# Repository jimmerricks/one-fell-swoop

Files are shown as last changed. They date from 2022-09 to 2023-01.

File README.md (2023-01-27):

# Swoop

A WIP fork of [David Barr's Sweep](https://github.com/davidphilipbarr/Sweep), which is itself based on the fabulous [Ferris by Pierre Chevalier](https://github.com/pierrechevalier83/ferris).

<span>
  <a href="https://discord.com/invite/JxfcFuUGhR">
    
  </a>
  
</span>

## Swoop MX / Howarya 🦞

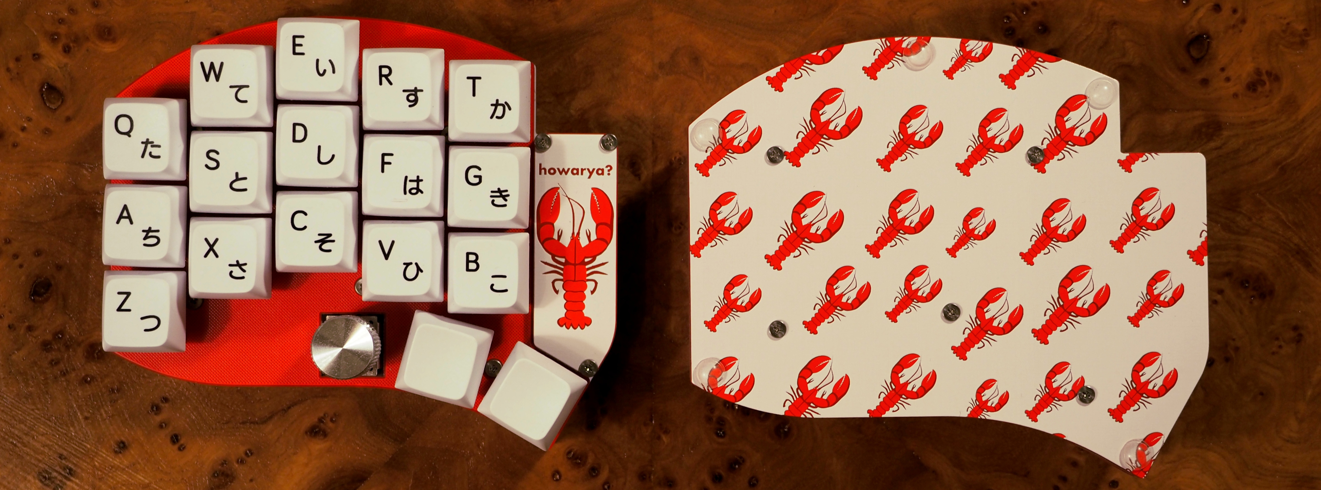
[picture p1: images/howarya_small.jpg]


| Front | Back |
| :---: | :---: |
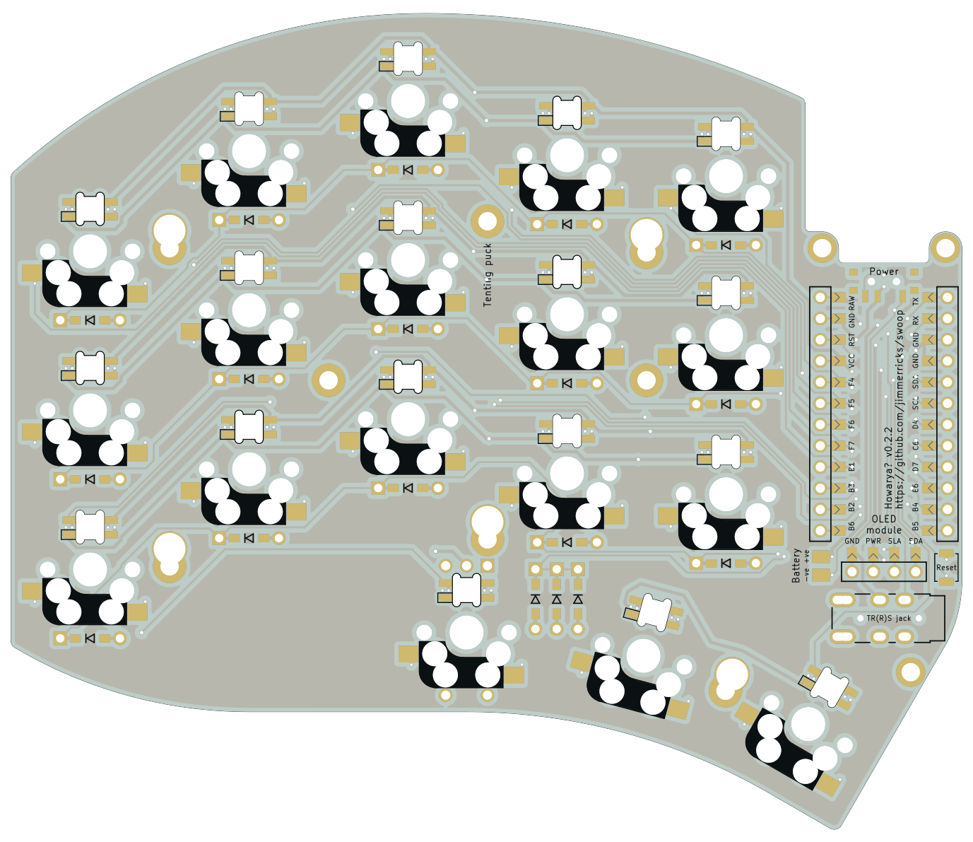
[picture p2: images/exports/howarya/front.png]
front
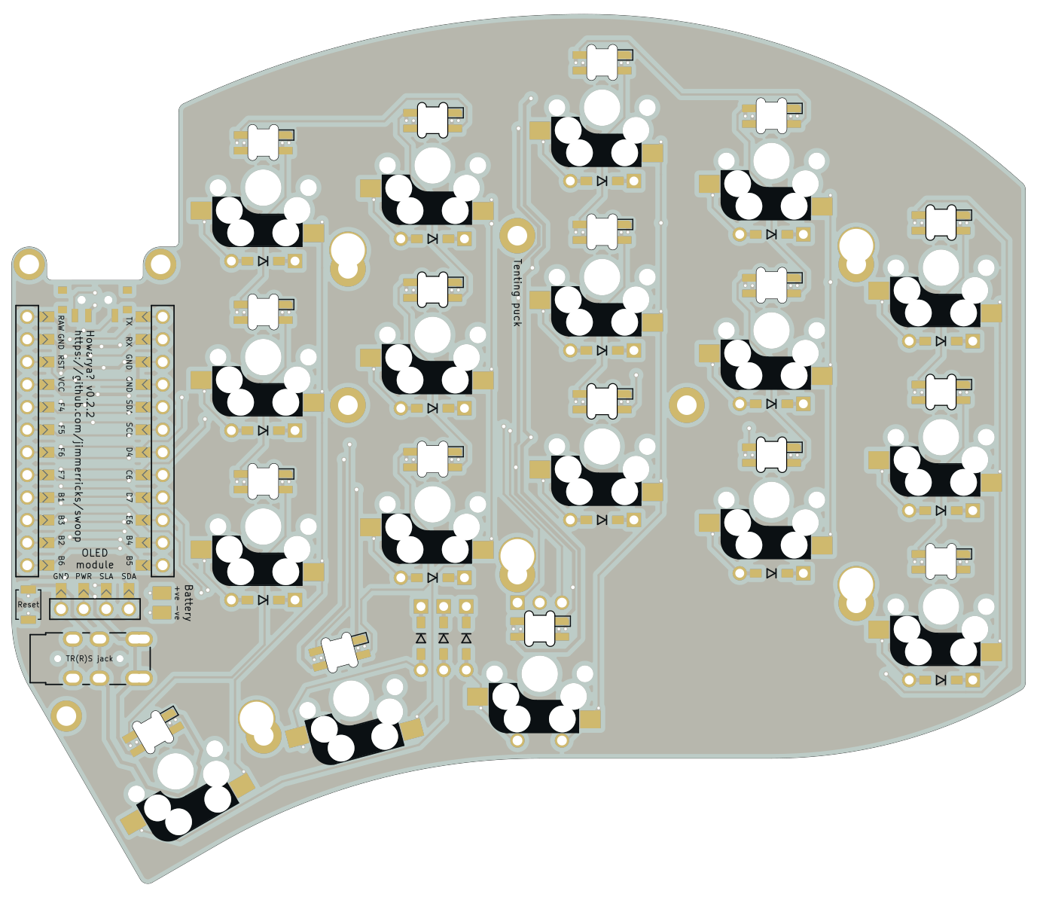
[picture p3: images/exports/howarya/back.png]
back
|  |  |

### Features
⭕ Cherry MX style switches  
⭕ Hotswap support  
⭕ Per-key RGB LEDs (mini-e)  
⭕ Up to 2 encoders  
⭕ Oled screens  
⭕ Power switch for battery management  
⭕ Bluetooth support w/ nice!nano  
⭕ Plate style case with mcu cover

### Components list

To build and use a Swoop MX you will need:

* 1× PCB Kit
* 2× promicro compatible boards or 2 nice!nanos.
* 34-36× Cherry MX style switches
* 34-36× Kailh hotswap sockets
* 34-36× SK6812 Mini-E RGB SMD Leds (optional; not recommended for wireless)
* 34-36× keycaps
* 36× diodes (Surface-mount or Through-hole)
* 2× Rotary encoders & knobs (optional; ALPS EC11)
* 2× OLED LCD Display 128x32 SSD1306 (optional)
* 2× reset switches (optional; B3U-1000P(M))
* Some little rubber feet/bumpers
* 2× power switches (wireless only; MSK 12C02)
* 2× lipo batteries (wireless only; 301230 or 301228)
* 1× TRRS (not TRS!) cable (wired only)
* 2× TRRS Jack [PJ-320A] (wired only)
* 1× USB Cable (depends on your micro-controller choice)  

**For the case:**

* 32× M2 Screws (3mm thread length)  
* 10× M2 Standoff for the plates (7mm)
* 6× M2 Standoff for the controller cover (8mm)

### How to build it

<a href="https://youtu.be/pvvNYPsMyz4" target="_blank">
  
</a>

### Firmware

The firmware is available in QMK as `bluebell/swoop`.  
You can get started by using QMK's [online configurator](https://config.qmk.fm/#/bluebell/swoop/LAYOUT_split_3x5_3). Or check the [Swoop README file](https://github.com/qmk/qmk_firmware/blob/master/keyboards/bluebell/swoop/readme.md) to see how to compile the firmware locally.

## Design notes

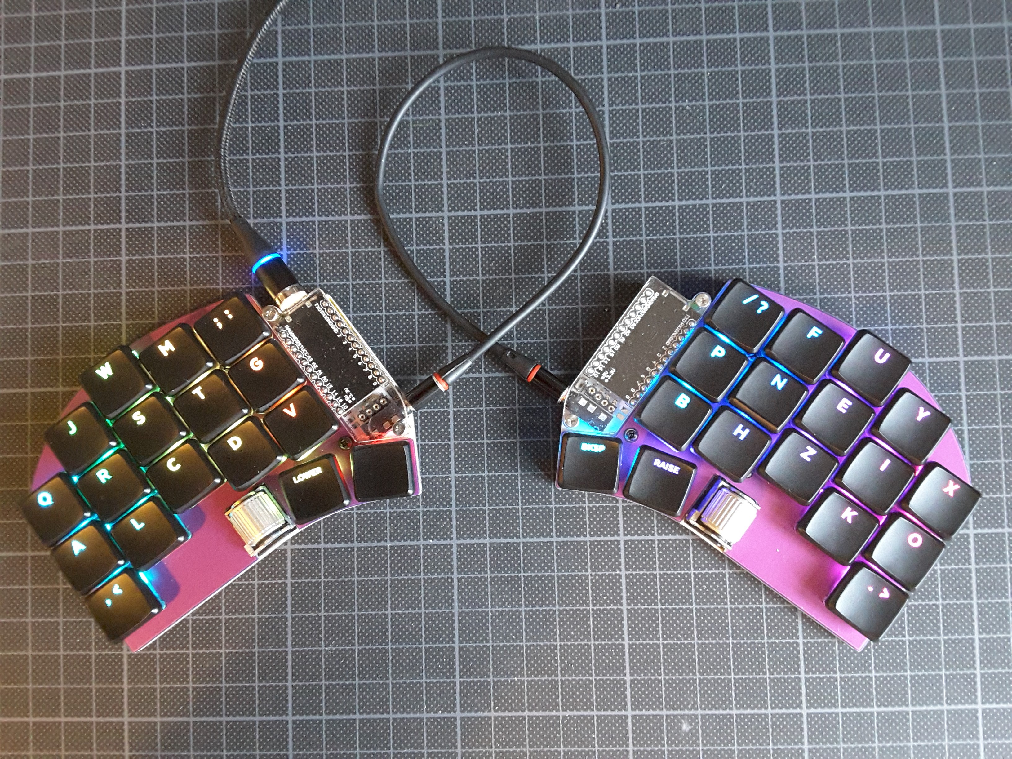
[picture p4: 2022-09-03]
images/swoop.jpg

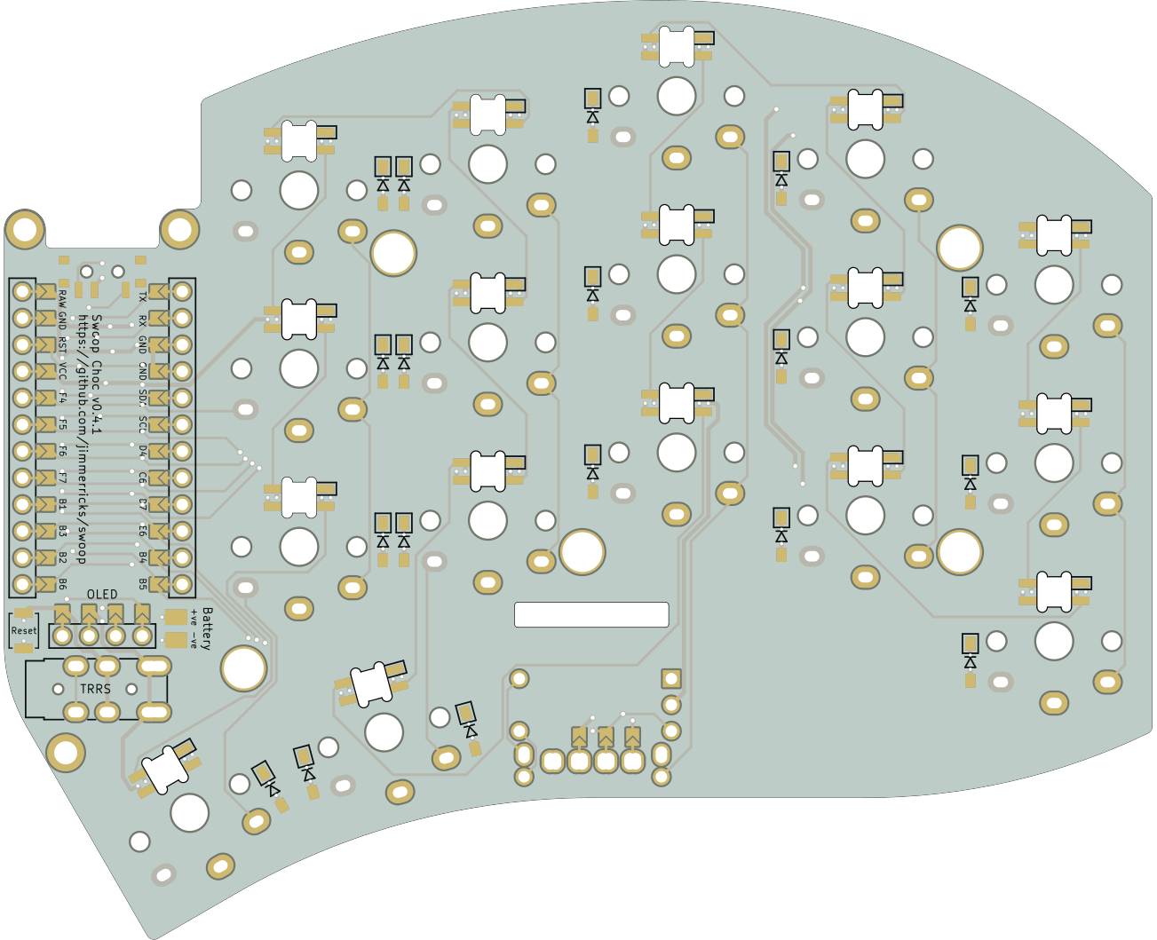
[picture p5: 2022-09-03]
images/exports/swoop/back.png

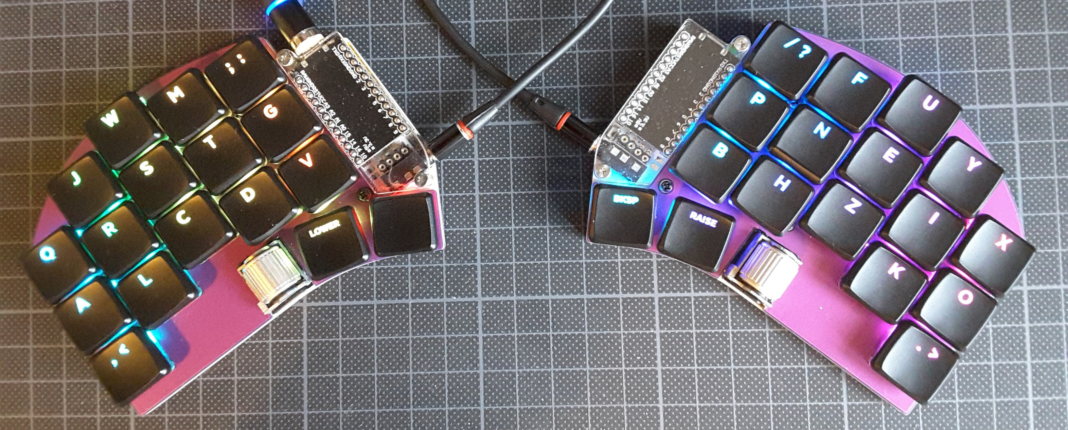
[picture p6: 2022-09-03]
images/swoop_small.jpg

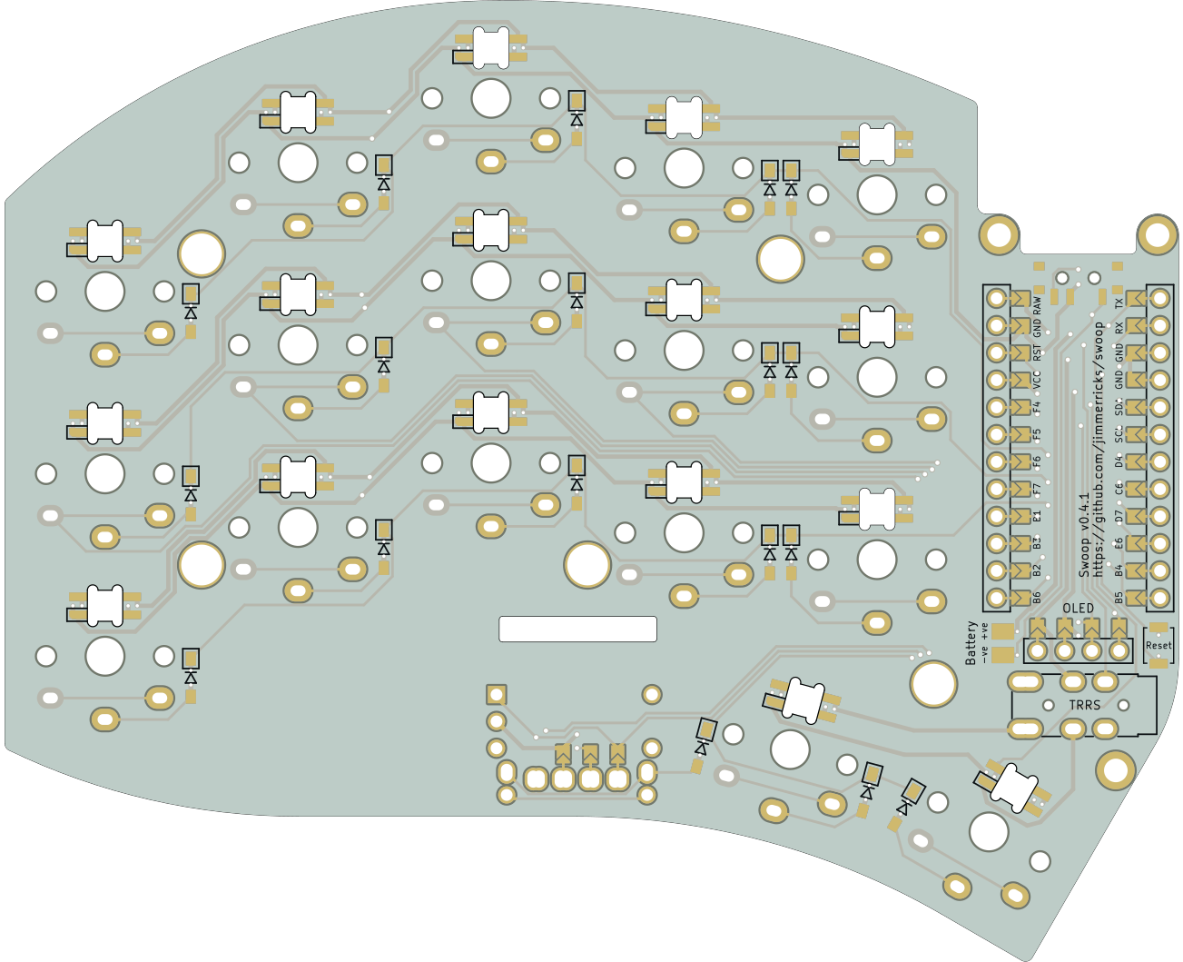
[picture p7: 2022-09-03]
images/exports/swoop/front.png

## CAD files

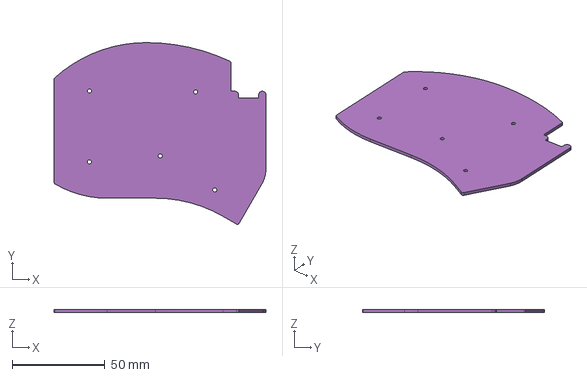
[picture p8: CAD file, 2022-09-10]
plates/swoop-mx/swoop-mx-base-plate/swoop-mx-plate-base-plate.step
114.0 x 97.8 x 1.60 mm

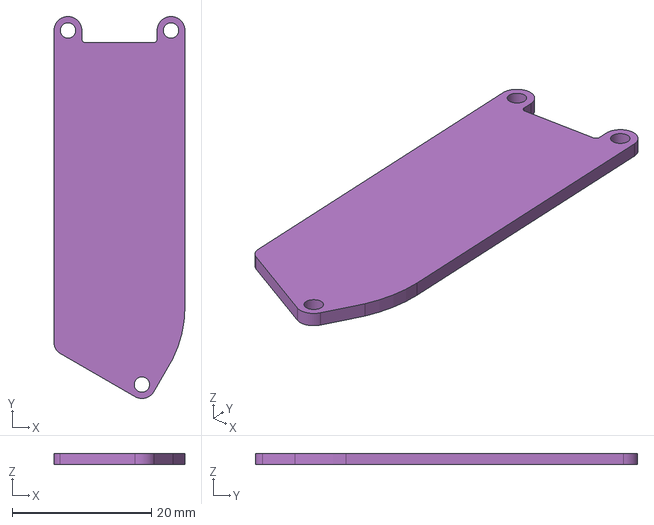
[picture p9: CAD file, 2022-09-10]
plates/swoop-mx/swoop-mx-cover/swoop-mx-plate-cover.step
18.8 x 54.8 x 1.60 mm

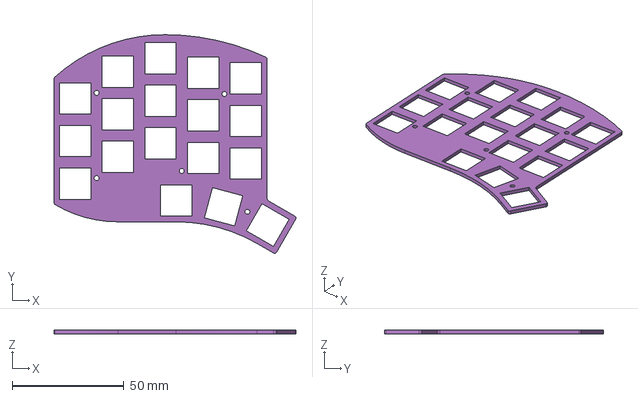
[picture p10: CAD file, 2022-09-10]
plates/swoop-mx/swoop-mx-switch-plate/swoop-mx-plate-switch-plate.step
108.2 x 97.8 x 1.60 mm

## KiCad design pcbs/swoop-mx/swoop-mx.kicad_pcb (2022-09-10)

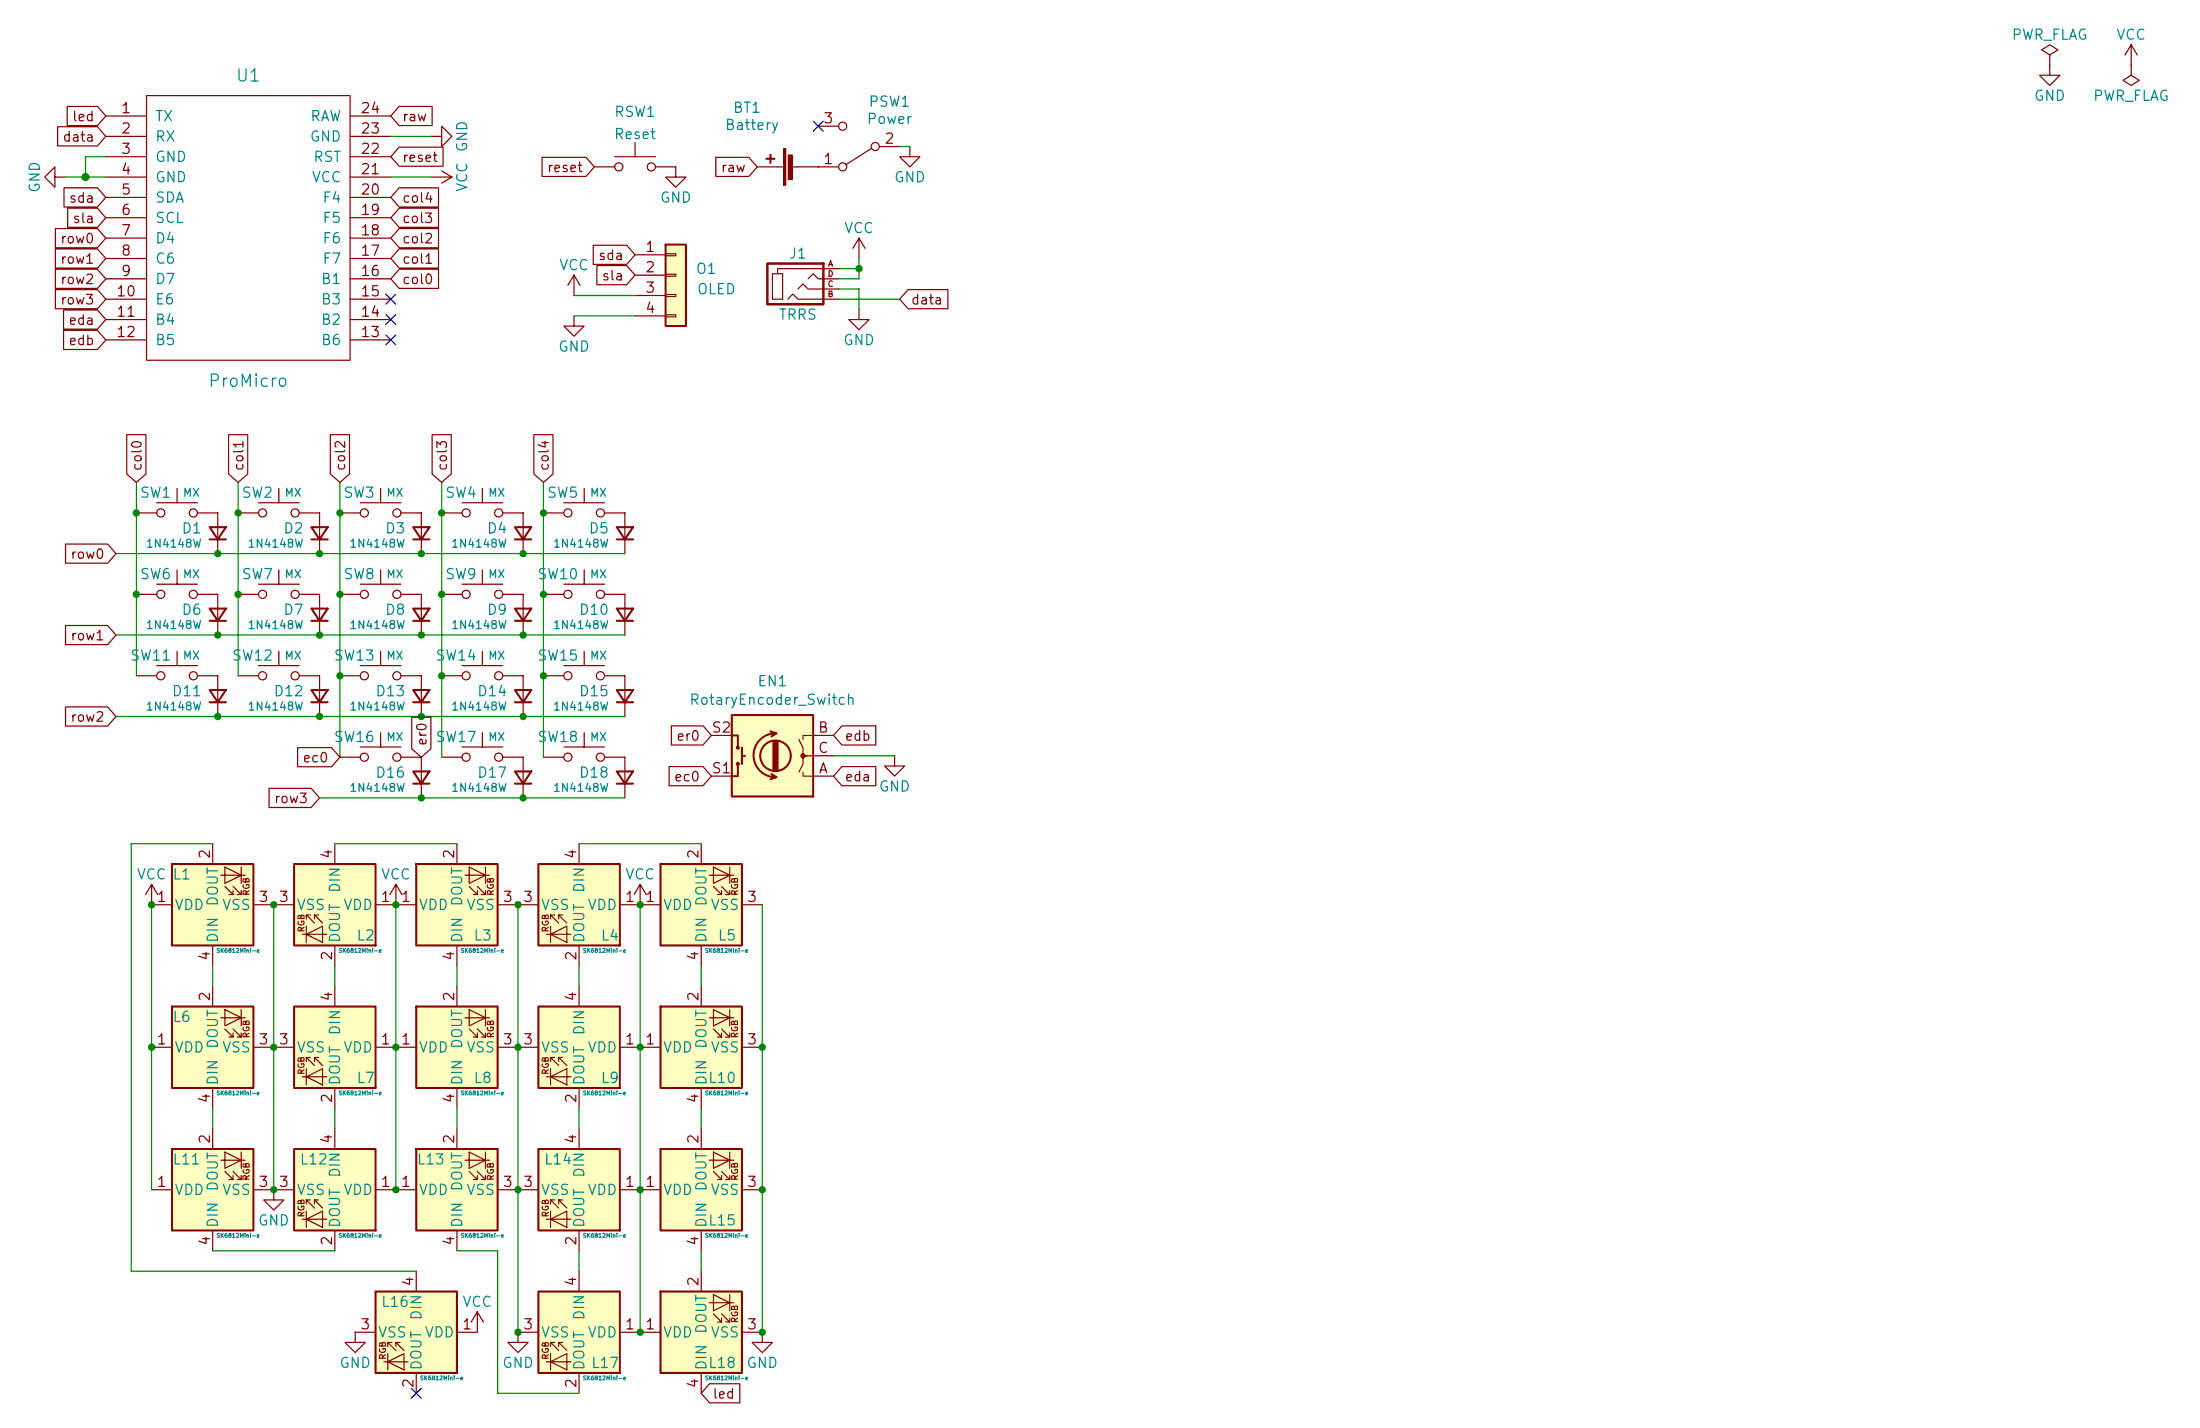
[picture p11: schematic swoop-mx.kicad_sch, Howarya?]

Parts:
BT1: Battery; Battery_pads_reversible
D1, D2, D3, D4, D5, D6, D7, D8, D9, D10, D11, D12, D13, D14, D15, D16, D17, D18: 1N4148W; D_SMD_TH
EN1: RotaryEncoder_Switch; RotaryEncoder
J1: TRRS; TRRS-3pin
L1, L2, L3, L4, L5, L6, L7, L8, L9, L10, L11, L12, L13, L14, L15, L16, L17, L18: SK6812Mini-e; SK6812_Mini_E; JLCPCB BOM 0
O1: OLED; OLED_jumpers
PSW1: Power
RSW1: Reset
SW1, SW2, SW3, SW4, SW5, SW6, SW7, SW8, SW9, SW10, SW11, SW12, SW13, SW14, SW15, SW16, SW17, SW18: MX; MX_socket_reversible
U1: ProMicro; ProMicro_jumpers

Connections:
GND: EN1.C, J1.C, L1.3 (VSS), L2.3 (VSS), L3.3 (VSS), L4.3 (VSS), L5.3 (VSS), L6.3 (VSS), L7.3 (VSS), L8.3 (VSS), L9.3 (VSS), L10.3 (VSS), L11.3 (VSS), L12.3 (VSS), L13.3 (VSS), L14.3 (VSS), L15.3 (VSS), L16.3 (VSS), L17.3 (VSS), L18.3 (VSS), O1.4, PSW1.2 (B), RSW1.2, U1.3 (GND), U1.4 (GND), U1.23 (GND)
unnamed: BT1.2 (-), PSW1.1 (A)
unnamed: D1.2 (A), SW1.2
unnamed: D2.2 (A), SW2.2
unnamed: D3.2 (A), SW3.2
unnamed: D4.2 (A), SW4.2
unnamed: D5.2 (A), SW5.2
unnamed: D6.2 (A), SW6.2
unnamed: D7.2 (A), SW7.2
unnamed: D8.2 (A), SW8.2
unnamed: D9.2 (A), SW9.2
unnamed: D10.2 (A), SW10.2
unnamed: D11.2 (A), SW11.2
unnamed: D12.2 (A), SW12.2
unnamed: D13.2 (A), SW13.2
unnamed: D14.2 (A), SW14.2
unnamed: D15.2 (A), SW15.2
unnamed: D17.2 (A), SW17.2
unnamed: D18.2 (A), SW18.2
unnamed: L1.2 (DOUT), L16.4 (DIN)
unnamed: L1.4 (DIN), L6.2 (DOUT)
unnamed: L2.2 (DOUT), L7.4 (DIN)
unnamed: L2.4 (DIN), L3.2 (DOUT)
unnamed: L3.4 (DIN), L8.2 (DOUT)
unnamed: L4.2 (DOUT), L9.4 (DIN)
unnamed: L4.4 (DIN), L5.2 (DOUT)
unnamed: L5.4 (DIN), L10.2 (DOUT)
unnamed: L6.4 (DIN), L11.2 (DOUT)
unnamed: L8.4 (DIN), L13.2 (DOUT)
unnamed: L10.4 (DIN), L15.2 (DOUT)
unnamed: L11.4 (DIN), L12.2 (DOUT)
unnamed: L7.2 (DOUT), L12.4 (DIN)
unnamed: L9.2 (DOUT), L14.4 (DIN)
unnamed: L13.4 (DIN), L17.2 (DOUT)
unnamed: L14.2 (DOUT), L17.4 (DIN)
unnamed: L15.4 (DIN), L18.2 (DOUT)
VCC: J1.A, J1.D, L1.1 (VDD), L2.1 (VDD), L3.1 (VDD), L4.1 (VDD), L5.1 (VDD), L6.1 (VDD), L7.1 (VDD), L8.1 (VDD), L9.1 (VDD), L10.1 (VDD), L11.1 (VDD), L12.1 (VDD), L13.1 (VDD), L14.1 (VDD), L15.1 (VDD), L16.1 (VDD), L17.1 (VDD), L18.1 (VDD), O1.3, U1.21 (VCC)
col0: SW1.1, SW6.1, SW11.1, U1.16 (B1)
col1: SW2.1, SW7.1, SW12.1, U1.17 (F7)
col2: EN1.S1, SW3.1, SW8.1, SW13.1, SW16.1, U1.18 (F6)
col3: SW4.1, SW9.1, SW14.1, SW17.1, U1.19 (F5)
col4: SW5.1, SW10.1, SW15.1, SW18.1, U1.20 (F4)
data: J1.B, U1.2 (RX)
eda: EN1.A, U1.11 (B4)
edb: EN1.B, U1.12 (B5)
er0: D16.2 (A), EN1.S2, SW16.2
led: L18.4 (DIN), U1.1 (TX)
raw: BT1.1 (+), U1.24 (RAW)
reset: RSW1.1, U1.22 (RST)
row0: D1.1 (K), D2.1 (K), D3.1 (K), D4.1 (K), D5.1 (K), U1.7 (D4)
row1: D6.1 (K), D7.1 (K), D8.1 (K), D9.1 (K), D10.1 (K), U1.8 (C6)
row2: D11.1 (K), D12.1 (K), D13.1 (K), D14.1 (K), D15.1 (K), U1.9 (D7)
row3: D16.1 (K), D17.1 (K), D18.1 (K), U1.10 (E6)
sda: O1.1, U1.5 (SDA)
sla: O1.2, U1.6 (SCL)

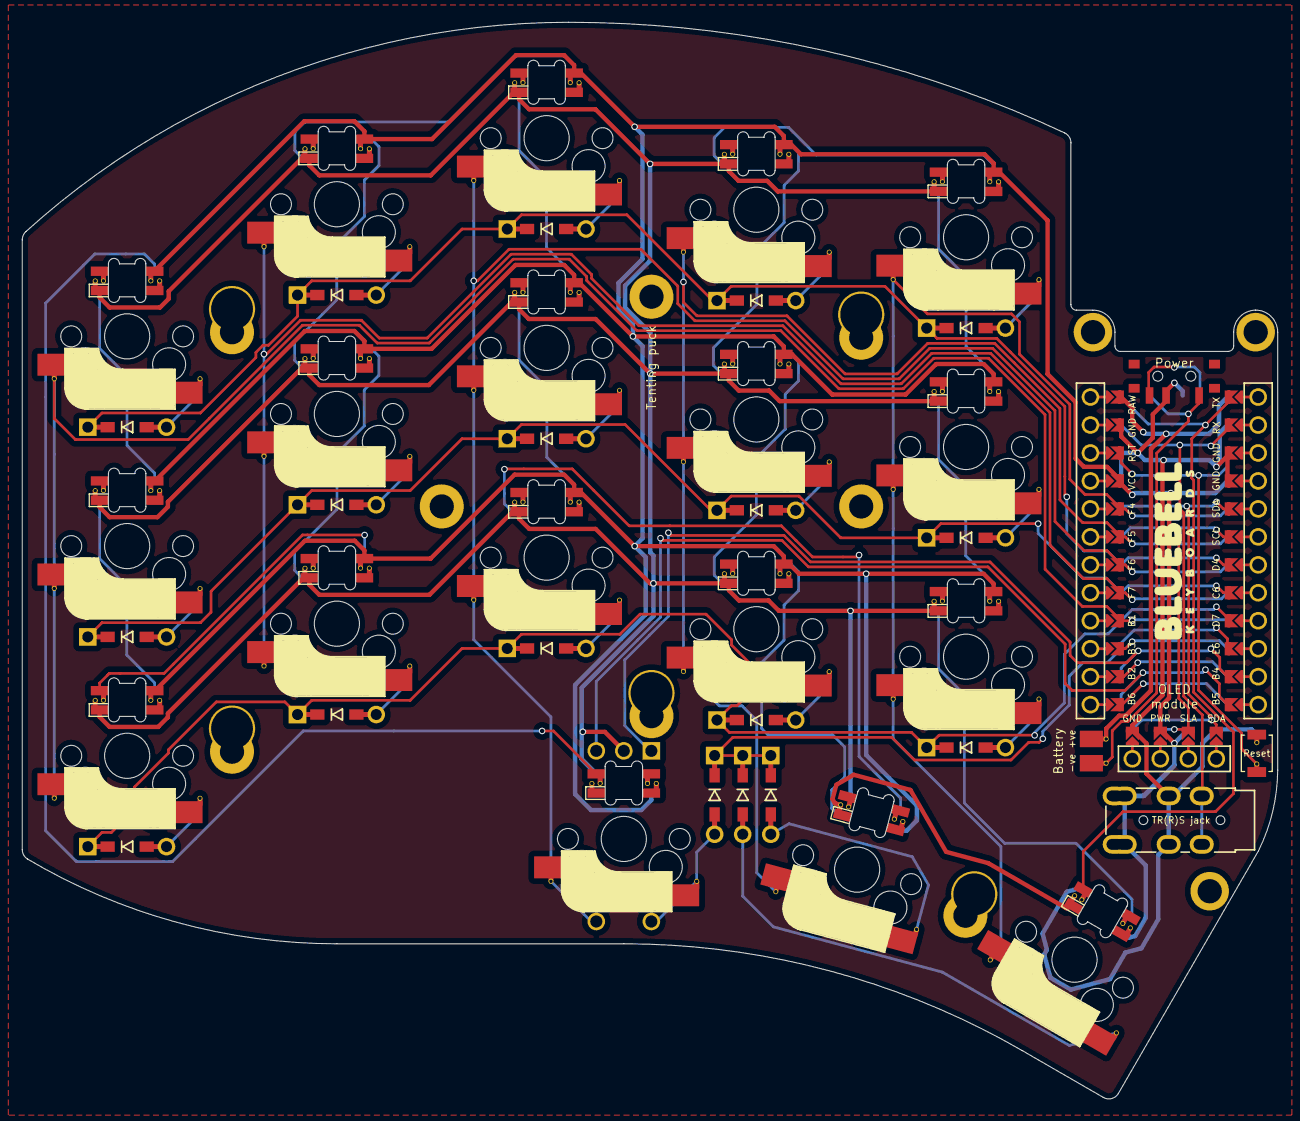
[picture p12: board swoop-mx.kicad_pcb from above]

Board: 2 copper layers, 114.0 x 97.8 mm, 70 parts (0 on the bottom side), 55 nets.

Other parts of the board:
H1, H2, H3, H4, H4#2: M2 Hole; M2_double_hole_4mm
PUCK1: SYM_Arrow45_Small; Tenting_puck
Ref**: Val**; M2_hole_3.5mm
Ref**#2, Ref**#3: Val**; M2_hole_3.5mm

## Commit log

2022-09-10 Removed the Swoop Choc (for now) and updated the Swoop MX to 2.2
    [swoop-mx-plate-base-plate.step, swoop-mx-plate-cover.kicad_pcb, swoop-mx-plate-cover.step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]
2022-09-10 Tidy up.
    [howarya.kicad_pcb, howarya.kicad_sch, howarya.sch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]
2022-09-10 Solid instead of hatch fill on plates.
    [swoop-mx-plate-cover.kicad_pcb]
2022-09-17 Add case hardware
2022-09-17 Fix gerber file extension
2022-12-18 Add diode requirement, build guide, firmware
2023-01-15 Update screw count
